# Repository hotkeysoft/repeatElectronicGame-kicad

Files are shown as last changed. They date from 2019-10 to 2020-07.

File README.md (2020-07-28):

# Wizard Electronic Game
Rev A October 2019

### Handheld Electronic Game
- ATmega328P microcontroller running at 12MHz
- 4 LEDs
- 4 buttons for play / mode selection
- Buzzer
- Tag-Connect for programming
- Runs on 3 AAA batteries

The microcontroller runs a [TMS1000-series emulator](https://github.com/hotkeysoft/emulators) I made (running in TMS1700 mode).

One ROM is loaded on the emulator: **Pocket Repeat** (by *Tandy/Radio-Shack*).  This is a Simon game clone.

Images
============
|Front | Back |
|---|---|
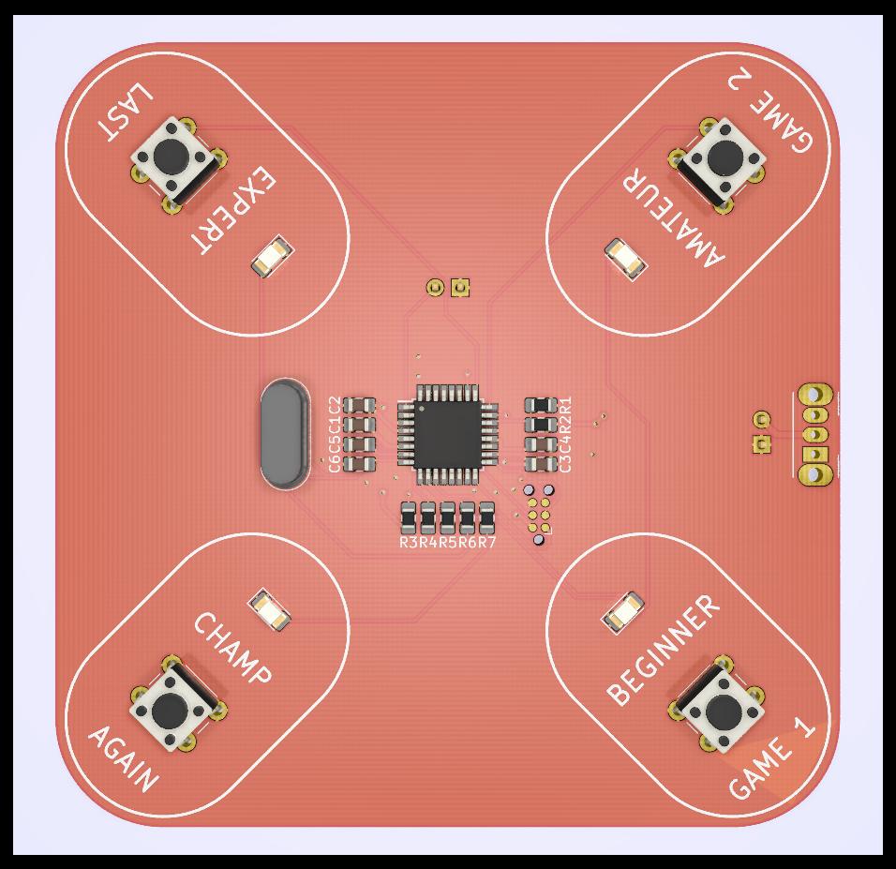
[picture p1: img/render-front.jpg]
Render Front
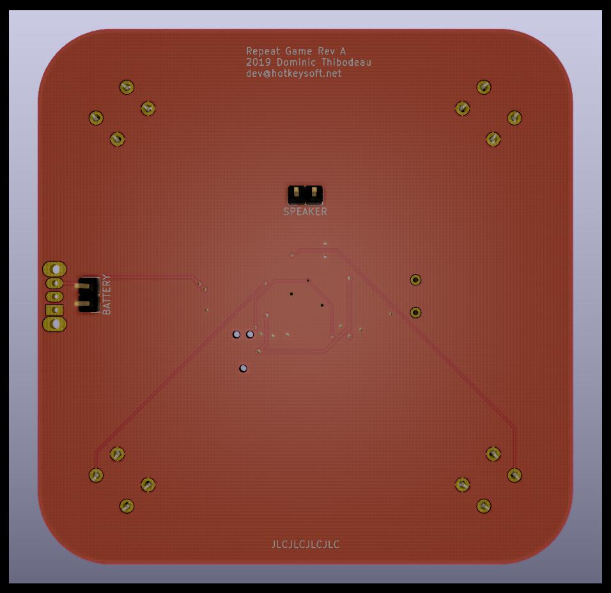
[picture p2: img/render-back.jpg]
Render Back
|||

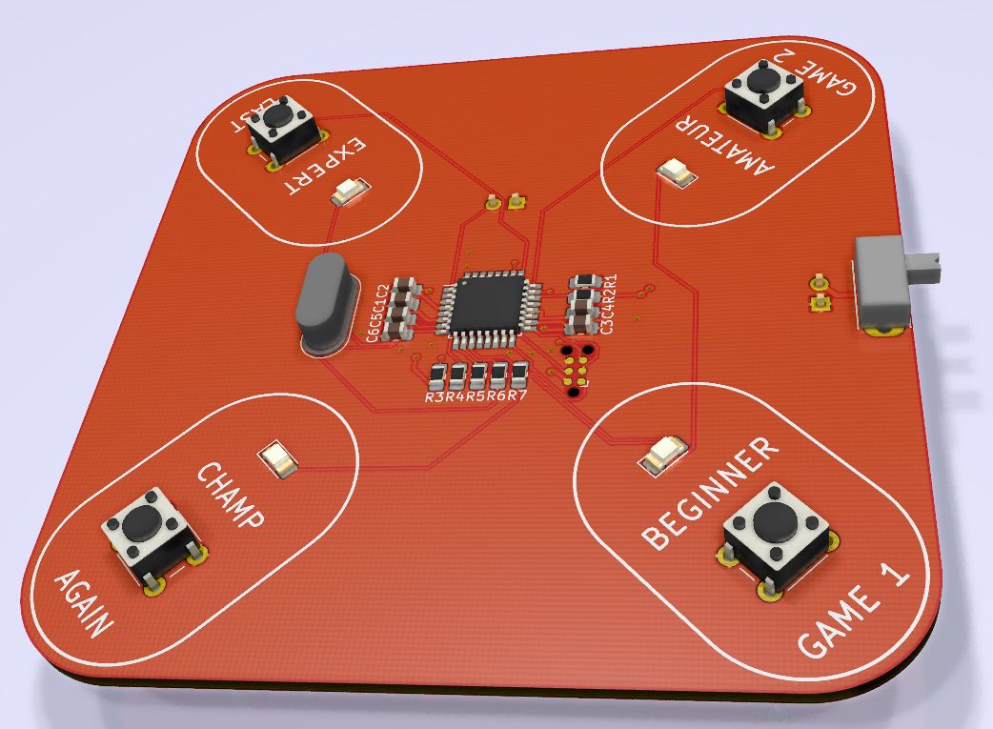
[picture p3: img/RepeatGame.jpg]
Render


### Schematics (pdf)
- [Complete schematics](./img/schema.pdf)

### PCB Images (svg)
- [Top](./img/pcb-front.svg)
- [Bottom](./img/pcb-back.svg)

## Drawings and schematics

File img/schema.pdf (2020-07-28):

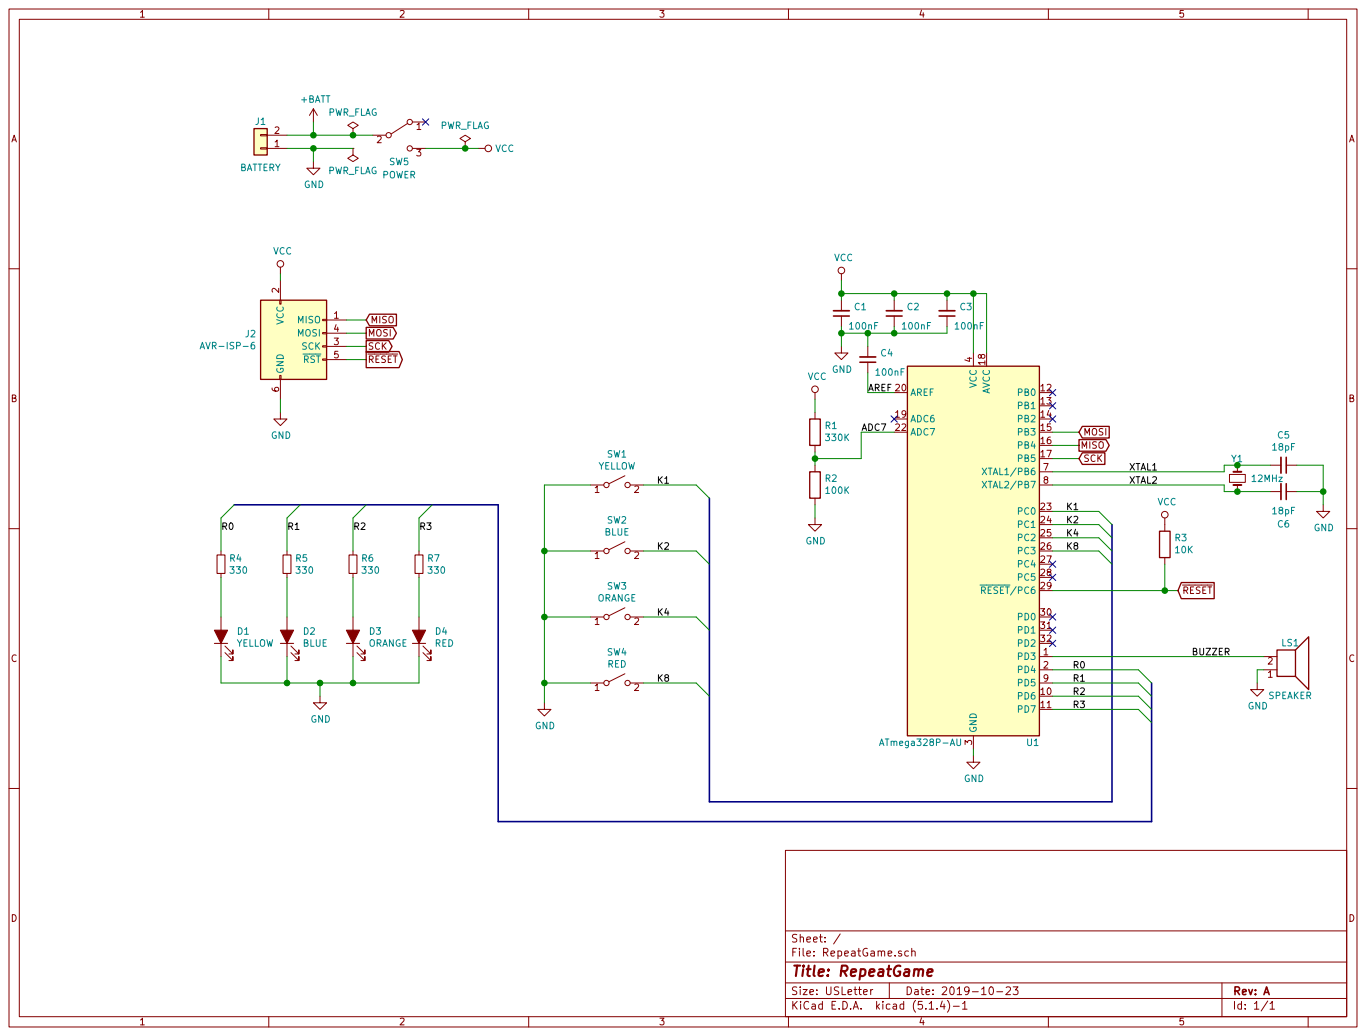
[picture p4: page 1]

2 SCK 3 MOSI 4 RST 5 GND

SCK RESET MOSI MISO

File: RepeatGame.sch Sheet: /
Id: 1/1 Title: RepeatGame

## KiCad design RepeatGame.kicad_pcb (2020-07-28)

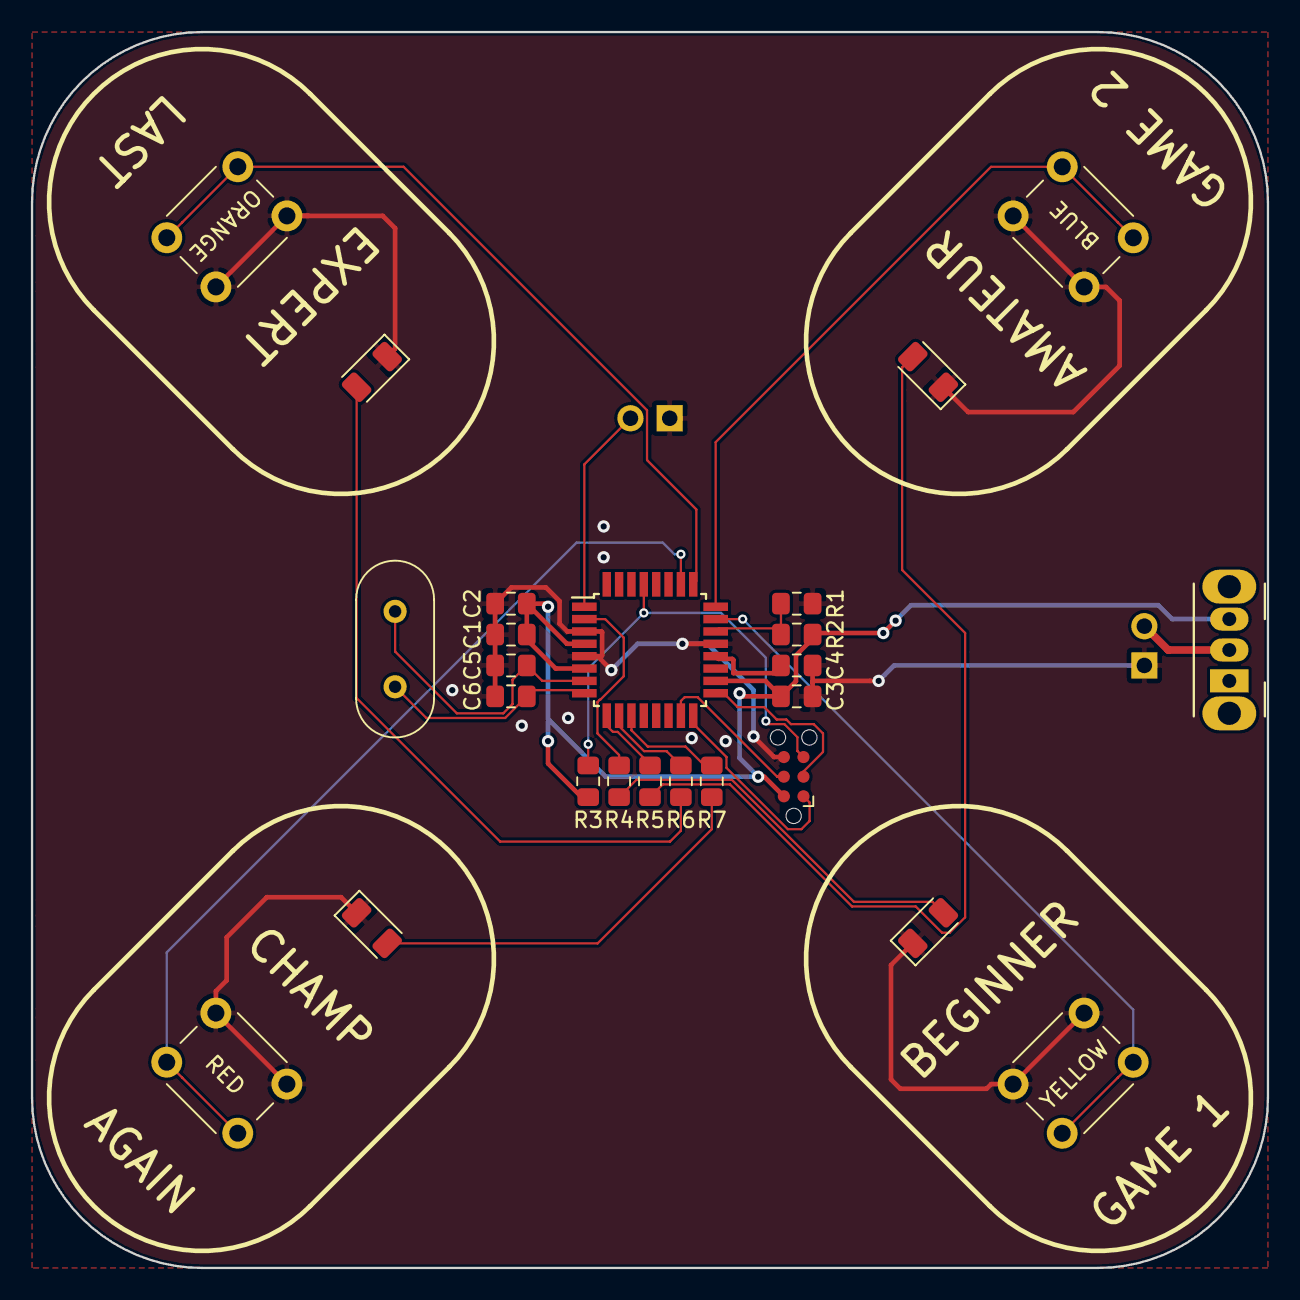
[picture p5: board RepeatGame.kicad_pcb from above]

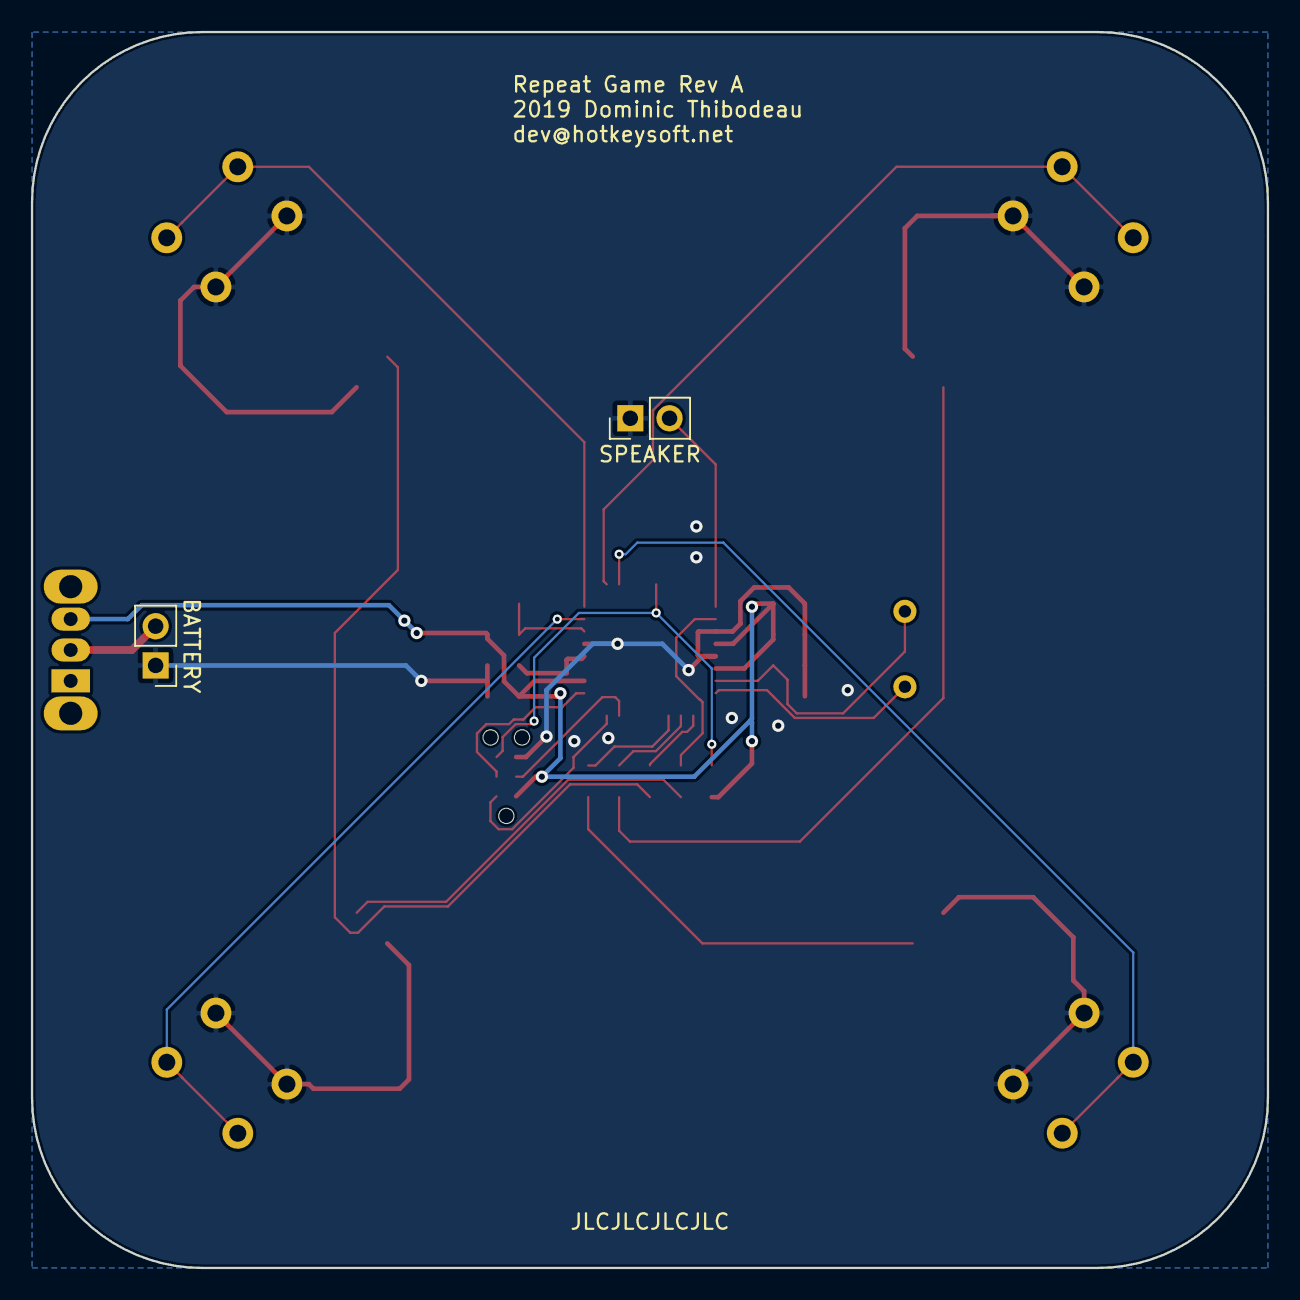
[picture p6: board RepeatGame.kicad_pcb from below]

Board: 2 copper layers, 80.0 x 80.0 mm, 27 parts (2 on the bottom side), 24 nets.

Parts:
C1, C2, C3, C4: 100nF; C_0805_2012Metric_Pad1.15x1.40mm_HandSolder
C5, C6: 18pF; C_0805_2012Metric_Pad1.15x1.40mm_HandSolder
D1: YELLOW; LED_1206_3216Metric
D2: BLUE; LED_1206_3216Metric
D3: ORANGE; LED_1206_3216Metric
D4: RED; LED_1206_3216Metric
J1: BATTERY; PinHeader_1x02_P2.54mm_Vertical
J2: AVR-ISP-6; Tag-Connect_TC2030-IDC-NL_2x03_P1.27mm_Vertical
LS1: SPEAKER; PinHeader_1x02_P2.54mm_Vertical
R1: 330K; R_0805_2012Metric_Pad1.15x1.40mm_HandSolder
R2: 100K; R_0805_2012Metric_Pad1.15x1.40mm_HandSolder
R3: 10K; R_0805_2012Metric_Pad1.15x1.40mm_HandSolder
R4, R5, R6, R7: 330; R_0805_2012Metric_Pad1.15x1.40mm_HandSolder
SW1: YELLOW; SW_PUSH_6mm
SW2: BLUE; SW_PUSH_6mm
SW3: ORANGE; SW_PUSH_6mm
SW4: RED; SW_PUSH_6mm
SW5: POWER; SW_CuK_OS102011MA1QN1_SPDT_Angled
U1: ATmega328P-AU; TQFP-32_7x7mm_P0.8mm
Y1: 12MHz; Crystal_HC49-4H_Vertical

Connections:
+BATT: J1.2, SW5.2
/ADC7: R1.1, R2.2, U1.22
/AREF: C4.1, U1.20
/BUZZER: LS1.2, U1.1
/K1: SW1.2, U1.23
/K2: SW2.2, U1.24
/K4: SW3.2, U1.25
/K8: SW4.2, U1.26
/R0: R4.1, U1.2
/R1: R5.1, U1.9
/R2: R6.1, U1.10
/R3: R7.1, U1.11
/XTAL1: C5.2, U1.7, Y1.1
/XTAL2: C6.2, U1.8, Y1.2
GND: C1.1, C2.1, C3.1, C4.2, C5.1, C6.1, D1.1, D2.1, D3.1, D4.1, J1.1, J2.6, LS1.1, R2.1, SW1.1, SW2.1, SW3.1, SW4.1, U1.3, U1.5, U1.21
MISO: J2.1, U1.16
MOSI: J2.4, U1.15
unnamed: D1.2, R4.2
unnamed: D2.2, R5.2
unnamed: D3.2, R6.2
unnamed: D4.2, R7.2
SCK: J2.3, U1.17
VCC: C1.2, C2.2, C3.2, J2.2, R1.2, R3.2, SW5.3, U1.4, U1.6, U1.18
~RESET: J2.5, R3.1, U1.29

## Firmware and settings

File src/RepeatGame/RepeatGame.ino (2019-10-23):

#include "rom.h"
#include "TMS1000.h"

#define K1 A0
#define K2 A1
#define K4 A2
#define K8 A3

#define O6 3

#define R0 4
#define R1 5
#define R2 6
#define R3 7

// Buttons connected to K1-K8
void inputKCallback() {
      TMS1000::g_cpu.K = (PINC & 15) ^ 15;
}

// LED connected to R0-R3
void outputRCallback(TMS1000::BYTE pin, bool state) {
  digitalWrite(R0+pin, state);
}

void outputOCallback(TMS1000::BYTE val) {
  digitalWrite(O6, val & 8);
}

void setup() {
  pinMode(K1, INPUT_PULLUP);
  pinMode(K2, INPUT_PULLUP);
  pinMode(K4, INPUT_PULLUP);
  pinMode(K8, INPUT_PULLUP);  

  pinMode(R0, OUTPUT);
  pinMode(R1, OUTPUT);
  pinMode(R2, OUTPUT);
  pinMode(R3, OUTPUT);

  pinMode(O6, OUTPUT);
   
  TMS1000::Init(TMS1000::CPU_TMS1700, 512, 32); 
  TMS1000::SetInputKCallback(inputKCallback);
  TMS1000::SetOutputOCallback(outputOCallback);
  TMS1000::SetOutputRCallback(outputRCallback);
  TMS1000::g_memory.ROM = rom;
  TMS1000::Reset();
}

void loop() {
  TMS1000::Step();
  delayMicroseconds(10);
}

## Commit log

2019-10-23 Added source
    [RepeatGame.kicad_pcb, RepeatGame.sch]
2020-07-28 Updated paths, added submodule commonlib
    [RepeatGame.kicad_pcb]
